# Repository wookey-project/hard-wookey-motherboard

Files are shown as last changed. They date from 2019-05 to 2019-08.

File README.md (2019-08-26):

# WooKey Mainboard PCB

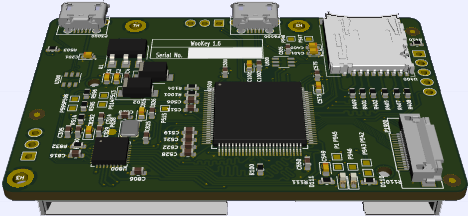
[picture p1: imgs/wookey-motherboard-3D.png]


## Introduction

Wookey | https://wookey-project.github.io/
Copyright 2018 ANSSI

Authors: The Wookey project Team <wookey@ssi.gouv.fr>

The Wookey from [ANSSI](https://www.ssi.gouv.fr) is an open source
hardware design, implementing an Encrypted Flash Drives.

This repository is aimed towards developers.

### Revision information

This directory contains the hardware design for the Wookey board, first public version (Wookey V2).

### PCB editing tools

All PCB files (schematic and PCB layout) have been designed using the KiCad EDA.
This Cross Platform and Open Source Electronics Design Automation Suite can be downloaded
on http://kicad-pcb.org/.

## Production files generation 101

### Configure the project

KiCad binaries location may change regarding your operating system.
This is why you have to set your environment.
This is done by sourcing the `setenv.sh` script. This script exports
all paths that are required in order to automaticaly generate the production files.

Most of the time, the paths proposed in this script are not the one you use in your specific installation.
The `setenv.sh` script support easy variables overloading by including a `setenv.local.sh` script file if this file exists in the same directory.
If you need to overload some of the variables of the `setenv.sh` script, just add them to your own `setenv.local.sh` file.
Here is an example to define KiCad environement path on Apple Mac OS.

```
  $ echo "export PYTHON_BIN_PATH = /Applications/KiCad/kicad.app/Contents/Frameworks/Python.framework/Versions/2.7/bin/python" > setenv.local.sh
  $ source setenv.sh
  Loading local SDK settings...
  =========================================================
  === Kicad environment configuration
  =========================================================
  PYTHON_BIN_PATH   = /Applications/KiCad/kicad.app/Contents/Frameworks/Python.framework/Versions/2.7/bin/python
  PYTHON_PATH     = /Applications/Kicad/kicad.app/Contents/Frameworks/python/site-packages
  BOM_GEN_PATH = /Applications/Kicad/kicad.app/Contents/SharedSupport/plugins/bom2grouped_csv.xsl
  TOOLS_PATH = ../../../tools
  =========================================================
```

The production files can be generated using the following command.

```
$ make
```

This will generate the production files in a new sub directory.
The directory name may differ according the project your are working with.

## PCB Pinout

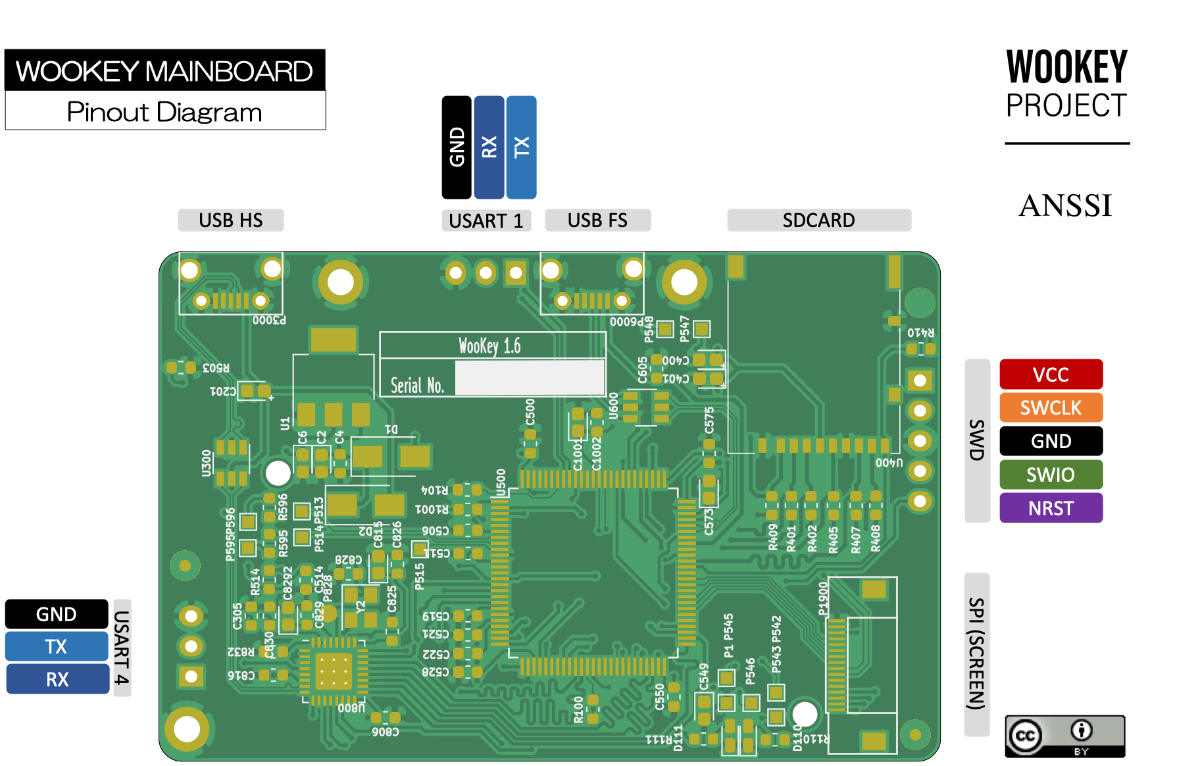
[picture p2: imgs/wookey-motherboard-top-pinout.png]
Pinout


## PCB Layers

### PCB TOP layer

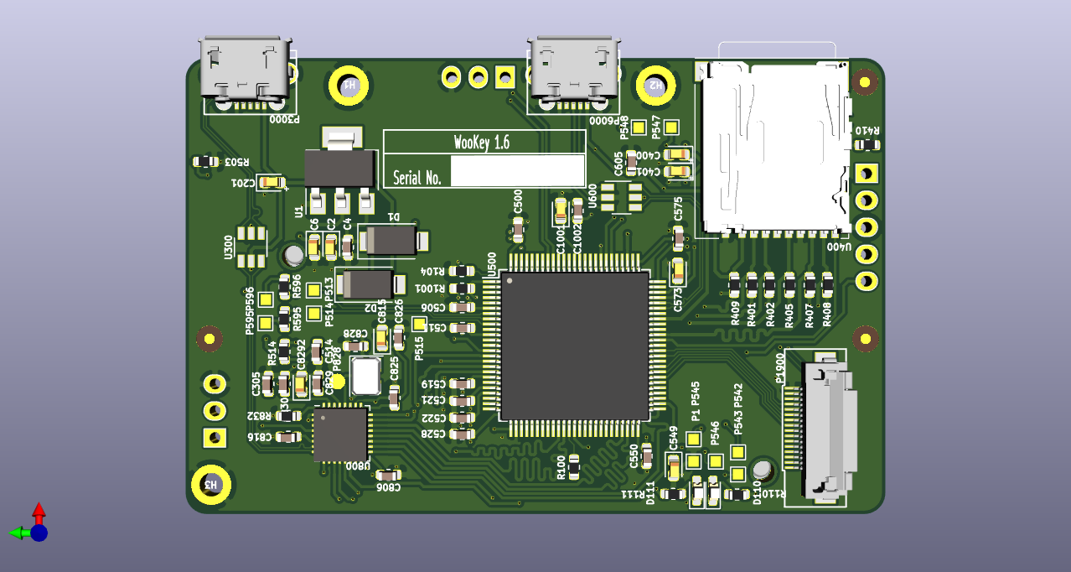
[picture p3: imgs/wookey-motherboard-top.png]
TOP


### PCB BOTTOM layer

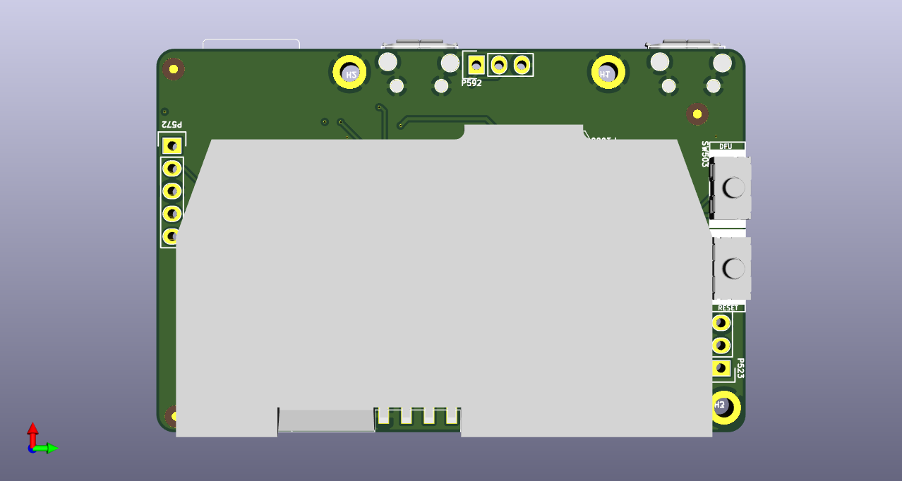
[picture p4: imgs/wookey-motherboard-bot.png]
BOT


### Layers

Order and type of copper layers:
  TOP:  signal, front components
  GND:  ground plane
  PWR:  ground and power plane
  BOT:  signal, back components

### Stackup
4 layers, 1.6mm thickness
Outer layers 1 oz base copper foil
Inner layers 0.5 oz base copper foil

Electroless Nickel Immersion Gold (ENIG) surface finish

solder resist   0.0254mm
copper          0.0356mm    L1 (TOP)
FR408 prepreg   0.1702mm
copper          0.0178mm    L2 (GND)
FR408           1.1938mm
copper          0.0178mm    L3 (PWR)
FR408 prepreg   0.1702mm
copper          0.0356mm    L4 (BOT)
solder resist   0.0254mm

The substrate for both the core and prepreg is FR408,
with a dielectric constant of 3.66 at 1GHz.
The prepreg is comprised of 2 layers of Isola 2113.

## Regulatory compliance & handling

The Wookey board is intended for use as a development platform for hardware
or software. The board is an open system design, which does not include a
shielded enclosure. This may cause interference to other electrical or
electronic devices in close proximity. In a domestic environment, this product
may cause radio interference in which case the user may be required to take
adequate measures. In addition, this board should not be used near any medical
equipment or RF devices.

The board is sensitive to ESD. Hold the board only by its edges. After removing
the board from its box, place it on a grounded, static-free surface.

The board can become hot, like any fan-less design, during continuous high CPU
loads, mind its temperature while handling it.

## License

Wookey | https://wookey-project.github.io/

Copyright 2019 ANSSI

Authors: The Wookey project Team <wookey@ssi.gouv.fr>

This is an open hardware design licensed under the terms of the CERN Open
Hardware Licence (OHL) v1.2.

You may redistribute and modify this documentation under the terms of the CERN
OHL v.1.2 (http://ohwr.org/cernohl). This documentation is distributed WITHOUT
ANY EXPRESS OR IMPLIED WARRANTY, INCLUDING OF MERCHANTABILITY, SATISFACTORY
QUALITY AND FITNESS FOR A PARTICULAR PURPOSE. Please see the CERN OHL v.1.2 for
applicable conditions.

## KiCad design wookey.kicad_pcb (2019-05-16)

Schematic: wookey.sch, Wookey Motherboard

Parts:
FID1, FID2, FID3: FIDUCIAL; Fiducial_1mm_Dia_2.54mm_Outer_CopperTop
FID4, FID5, FID6: FIDUCIAL; Fiducial_1mm_Dia_2.54mm_Outer_CopperBottom
H1: H1; MountingHole_2.2mm_M2_ISO14580_Pad
H2: H2; MountingHole_2.2mm_M2_ISO14580_Pad
H3: H3; MountingHole_2.2mm_M2_ISO14580_Pad

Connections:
GND: H1.1, H2.1, H3.1; also elsewhere on the board

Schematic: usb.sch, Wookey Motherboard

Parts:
C201, C815, C8292: 4.7uF; CP_EIA-1608-08_AVX-J; MFG Part Num TLCJ475M010XTA
C305, C605, C806, C816, C825, C826, C829, C830: 100nF; C_0603_1608Metric; MFG Part Num 0603YC104JAT2A
C828: 0.01uF; C_0603_1608Metric; MFG Part Num C0603C103K2RACTU
P828: XI; Measurement_Point_Round-SMD-Pad_Small
P3000, P6000: USB_FS_OTG; USB_Micro-B-MOLEX_105017-0001; MFG Part Num 105017-0001
R832: 12K [1%]; R_0603_1608Metric; MFG Part Num MCT06030C1202FP500
U300, U600: USBLC6-2; TSOT-23-6; MFG Part Num USBLC6-2SC6
U800: USB3300; QFN-32-1EP_5x5mm_P0.5mm_EP3.1x3.1mm_ThermalVias; MFG Part Num USB3300-EZK
Y2: ASEMB-24.000MHZ-LY-T; Oscillator_SMD_Abracon_ASE-4Pin_3.2x2.5mm; MFG Part Num ASEMB-24.000MHZ-LY-T

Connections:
+3V3: C806.1, C816.1, C825.1, C828.1, C830.1, U800.6 (VDD3.3), U800.16 (VDD3.3), U800.25 (VDD3.3), U800.30 (VDD3.3), U800.31 (REG_EN), Y2.1 (STBY), Y2.4 (Vdd); also elsewhere on the board
/cpu/USB_FS_D+: U600.4 (Out2); also elsewhere on the board
/cpu/USB_FS_D-: U600.6 (Out1); also elsewhere on the board
/cpu/USB_FS_VBUS: C605.1, P6000.1 (VCC), U600.5 (VBUS); also elsewhere on the board
/cpu/USB_HS_HARD_RESET: U800.9 (RESET); also elsewhere on the board
/cpu/USB_HS_ULPI_CLK: U800.14 (CLKOUT); also elsewhere on the board
/cpu/USB_HS_ULPI_D0: U800.24 (DATA0); also elsewhere on the board
/cpu/USB_HS_ULPI_D1: U800.23 (DATA1); also elsewhere on the board
/cpu/USB_HS_ULPI_D2: U800.22 (DATA2); also elsewhere on the board
/cpu/USB_HS_ULPI_D3: U800.21 (DATA3); also elsewhere on the board
/cpu/USB_HS_ULPI_D4: U800.20 (DATA4); also elsewhere on the board
/cpu/USB_HS_ULPI_D5: U800.19 (DATA5); also elsewhere on the board
/cpu/USB_HS_ULPI_D6: U800.18 (DATA6); also elsewhere on the board
/cpu/USB_HS_ULPI_D7: U800.17 (DATA7); also elsewhere on the board
/cpu/USB_HS_ULPI_DIR: U800.12 (DIR); also elsewhere on the board
/cpu/USB_HS_ULPI_NXT: U800.11 (NXT); also elsewhere on the board
/cpu/USB_HS_ULPI_STP: U800.13 (STP); also elsewhere on the board
/cpu/USB_HS_VBUS: C201.2, C305.1, P3000.1 (VCC), U300.5 (VBUS), U800.4 (VBUS); also elsewhere on the board
/usb/USB_FS_CON_D+: P6000.3 (D+), U600.3 (In2)
/usb/USB_FS_CON_D-: P6000.2 (D-), U600.1 (In1)
/usb/USB_HS_CON_D+: P3000.3 (D+), U300.1 (In1)
/usb/USB_HS_CON_D-: P3000.2 (D-), U300.3 (In2)
/usb/USB_HS_D+: U300.6 (Out1), U800.7 (D+)
/usb/USB_HS_D-: U300.4 (Out2), U800.8 (D-)
GND: C201.1, C305.2, C605.2, C806.2, C815.2, C816.2, C825.2, C826.2, C828.2, C829.2, C830.2, C8292.2, P3000.5 (GND), P3000.6 (shield), P6000.5 (GND), P6000.6 (shield), R832.2, U300.2 (GND), U600.2 (GND), U800.1 (GND), U800.2 (GND), U800.33 (GND), Y2.2 (GND); also elsewhere on the board
unnamed: C815.1, C826.1, U800.15 (VDD1.8), U800.26 (VDD1.8)
unnamed: C829.1, C8292.1, U800.29 (VDDA1.8)
unnamed: P828.1, U800.28 (XI), Y2.3 (OUT)
unnamed: R832.1, U800.32 (RBIAS)

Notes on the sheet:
USB HIGH SPEED
USB FULLSPEED
Optional active high transceiver reset. This is the same as a write to the ULPI Reset, address 04h, bit 5. This does not reset the ULPI register set. This pin includes an integrated pull-down resistor to ground. If not used, this pin can be floated or connected to ground (recommended).
see qtzcry-app-notes.pdf (in datasheets)

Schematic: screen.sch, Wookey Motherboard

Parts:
BOM-ONLY1: FFC Jumper Cable; 0.5mm; 50mm; MFG Part Num 687716050002
BOM-ONLY2: FFC Jumper Cable; 0.5mm; 100mm; MFG Part Num 687716100002
BOM-ONLY3: FFC Jumper Cable; 0.5mm; 152mm; MFG Part Num 98266-0172
P1900: CONN_FPC16; FPC16_MOLEX_52892_1633; MFG Part Num 52892-1633

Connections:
+3V3: P1900.1; also elsewhere on the board
/cpu/SCREEN_~D~C: P1900.12; also elsewhere on the board
/cpu/SPI_MISO: P1900.3; also elsewhere on the board
/cpu/SPI_MOSI: P1900.2; also elsewhere on the board
/cpu/SPI_SCK: P1900.4; also elsewhere on the board
/cpu/TOUCH_BUSY: P1900.10; also elsewhere on the board
/cpu/TOUCH_IRQ: P1900.11; also elsewhere on the board
/cpu/~SPI_FLASH_CS: P1900.7; also elsewhere on the board
/cpu/~SPI_FONT_CS: P1900.8; also elsewhere on the board
/cpu/~SPI_SCREEN_CS: P1900.14; also elsewhere on the board
/cpu/~SPI_TOUCH_CS: P1900.9; also elsewhere on the board
/screen/SCREEN_RESET: P1900.13; also elsewhere on the board
GND: P1900.16; also elsewhere on the board

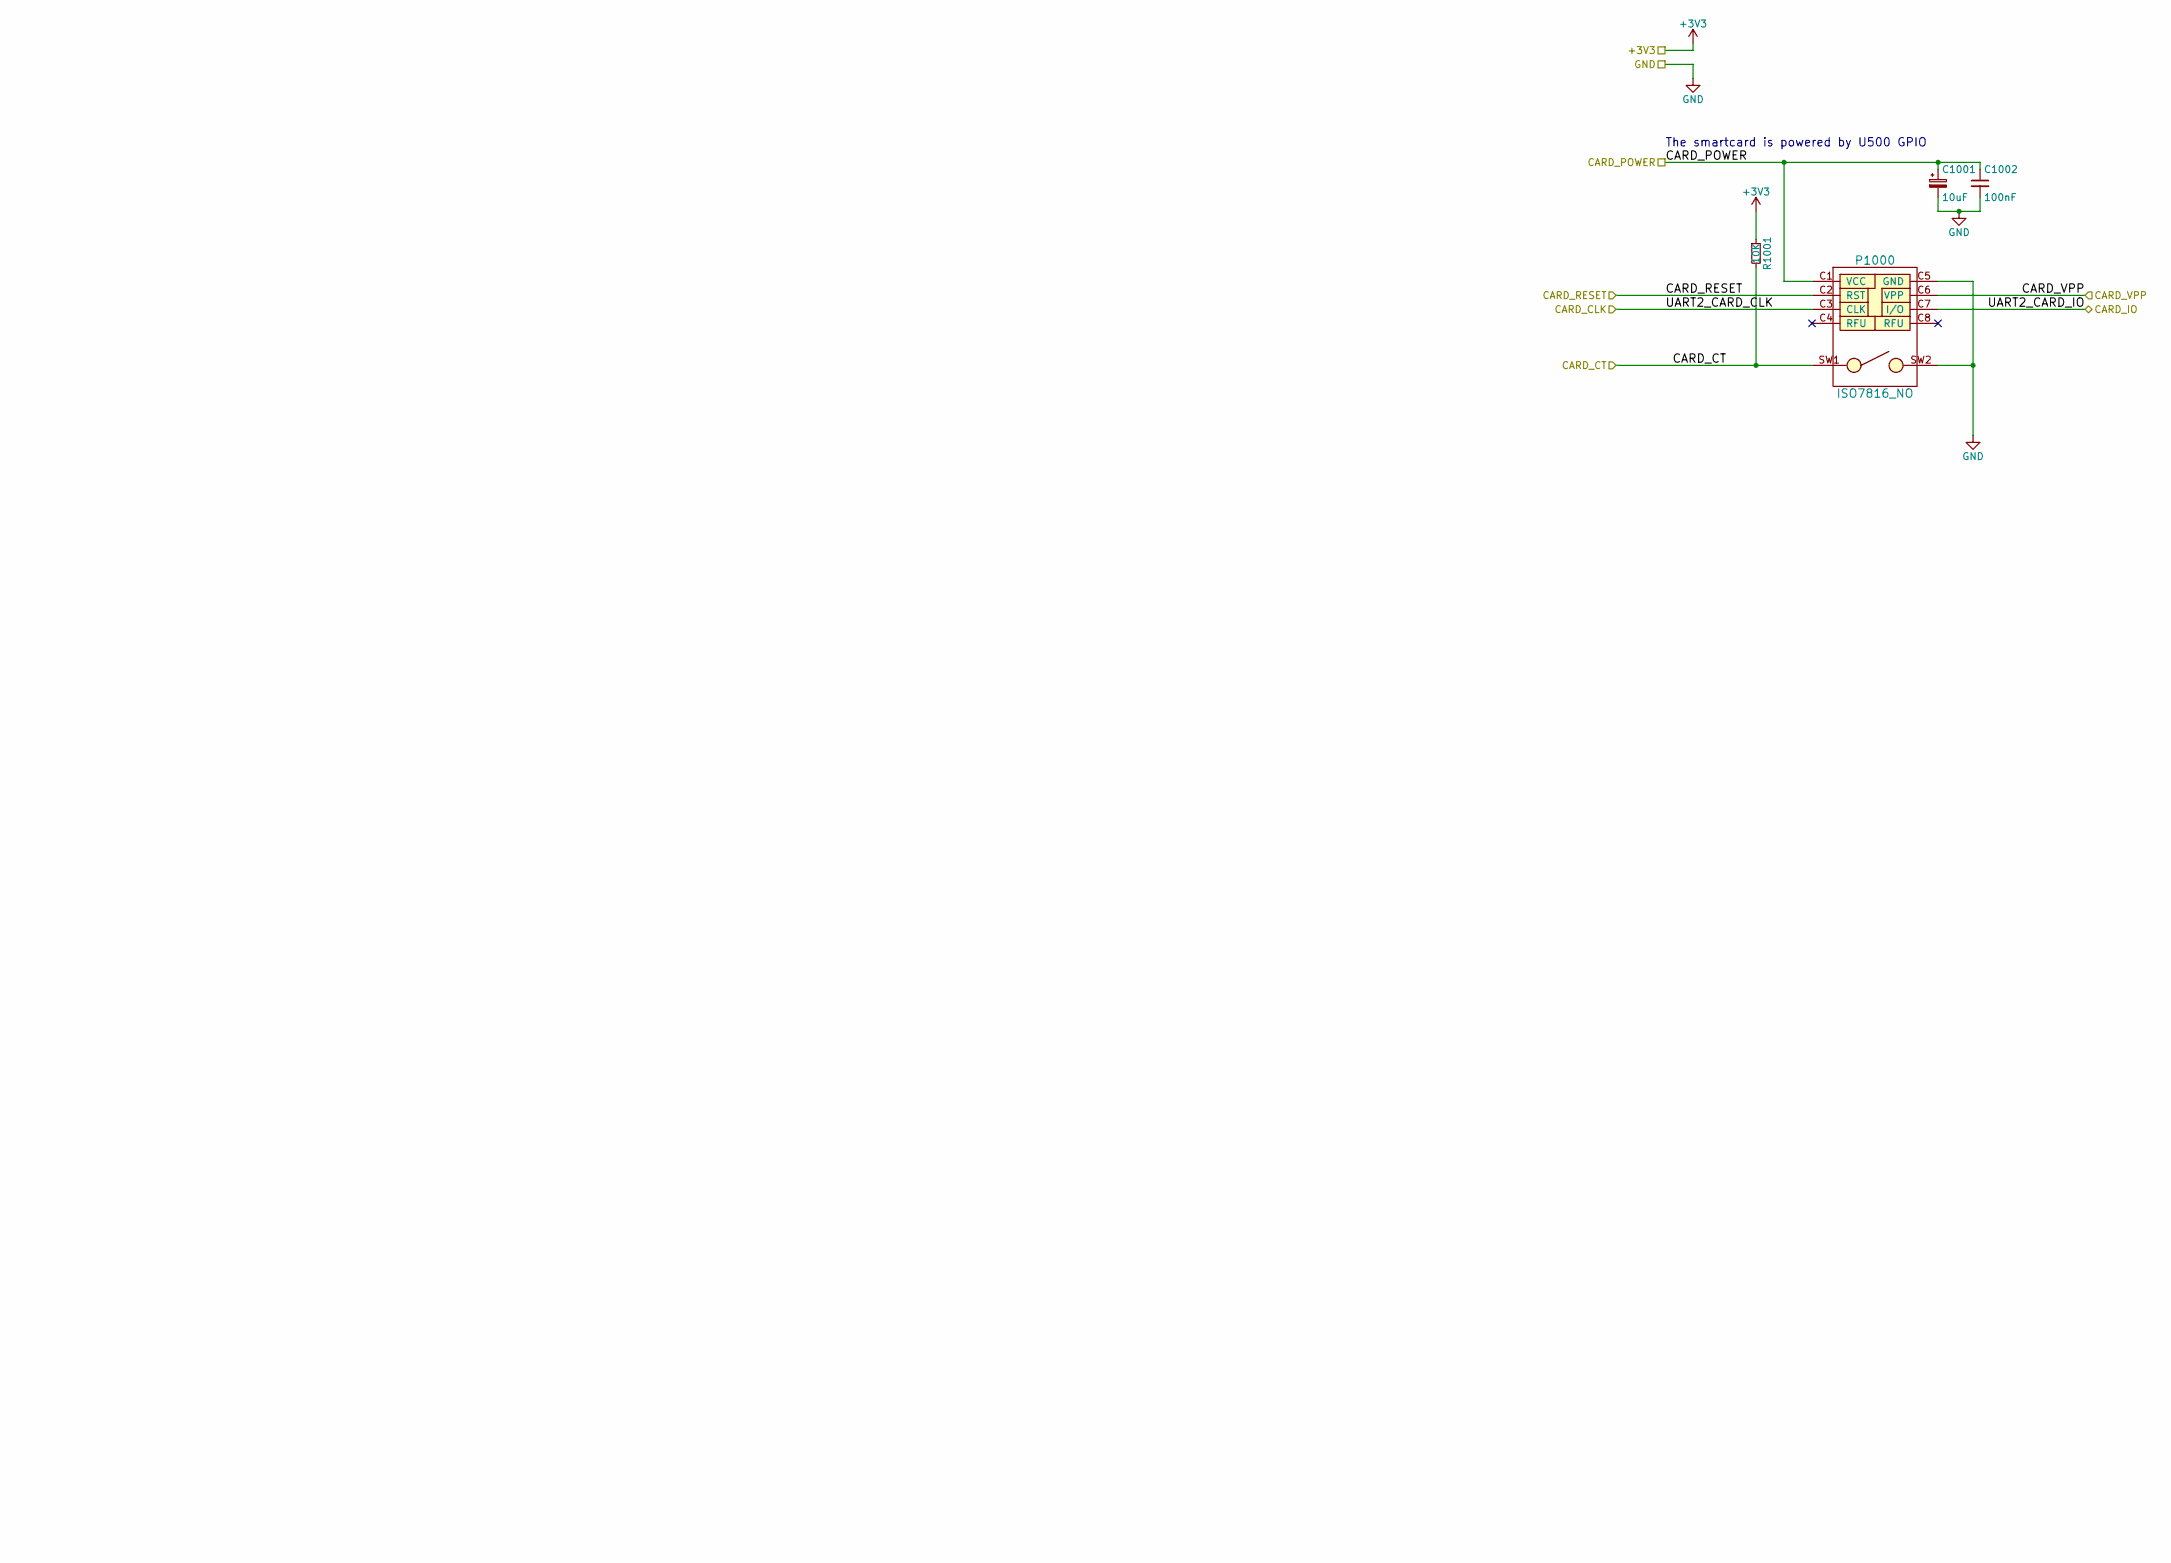
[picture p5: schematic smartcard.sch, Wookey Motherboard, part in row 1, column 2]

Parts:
C1001: 10uF; CP_EIA-1608-08_AVX-J; MFG Part Num F981A106MMA
C1002: 100nF; C_0603_1608Metric; MFG Part Num 0603YC104JAT2A
P1000: ISO7816_NO; VJW53666; MFG Part Num 7312P0225A13LF
R1001: 10K; R_0603_1608Metric; MFG Part Num CRCW060310K0FKEAHP

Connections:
+3V3: R1001.1; also elsewhere on the board
/cpu/CARD_CLK: P1000.C3 (CLK); also elsewhere on the board
/cpu/CARD_CT: P1000.SW1, R1001.2; also elsewhere on the board
/cpu/CARD_IO: P1000.C7 (I/O); also elsewhere on the board
/cpu/CARD_POWER: C1001.1, C1002.1, P1000.C1 (VCC); also elsewhere on the board
/cpu/CARD_RESET: P1000.C2 (RST); also elsewhere on the board
/cpu/CARD_VPP: P1000.C6 (VPP); also elsewhere on the board
GND: C1001.2, C1002.2, P1000.C5 (GND), P1000.SW2; also elsewhere on the board

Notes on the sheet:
The smartcard is powered by U500 GPIO

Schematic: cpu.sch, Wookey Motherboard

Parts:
C2, C6: 10uF; CP_EIA-1608-08_AVX-J; MFG Part Num F981A106MMA
C4, C500, C506, C511, C514, C519, C521, C522, C528, C550, C575: 100nF; C_0603_1608Metric; MFG Part Num 0603YC104JAT2A
C549, C573: 2.2uF; CP_EIA-1608-08_AVX-J; MFG Part Num TACL225M016XTA
D1, D2: STPS1L30A; D_SMA; MFG Part Num STPS1L30A
D110: LED BLUE; LED_0603_1608Metric_Castellated; MFG Part Num VLMB1300-GS08
D111: LED GREEN; LED_0603_1608Metric_Castellated; MFG Part Num VLMTG1300-GS08
P1: GND; TestPoint_Pad_1.0x1.0mm
P513: TP1; TestPoint_Pad_1.0x1.0mm
P514: TP2; TestPoint_Pad_1.0x1.0mm
P515: TP3; TestPoint_Pad_1.0x1.0mm
P523: UART4; Pin_Header_Straight_1x03; MFG Part Num 90121-0763
P542: TP4; TestPoint_Pad_1.0x1.0mm
P543: TP5; TestPoint_Pad_1.0x1.0mm
P545: TP7; TestPoint_Pad_1.0x1.0mm
P546: TP8; TestPoint_Pad_1.0x1.0mm
P547: TP9; TestPoint_Pad_1.0x1.0mm
P548: TP10; TestPoint_Pad_1.0x1.0mm
P572: DEBUG/PROG; Pin_Header_Straight_1x05; MFG Part Num TSW-105-07-L-S
P592: UART1; Pin_Header_Straight_1x03; MFG Part Num 90121-0763
P595: I2C1_SCL; TestPoint_Pad_1.0x1.0mm
P596: I2C1_SDA; TestPoint_Pad_1.0x1.0mm
R100, R503, R514: 10K; R_0603_1608Metric; MFG Part Num CRCW060310K0FKEAHP
R104, R110, R111: 470; R_0603_1608Metric; MFG Part Num CRCW0603470RFKEA
R595, R596: 47K; R_0603_1608Metric; MFG Part Num CRCW060347K0FKEA
SW503: DFU; KSR_TACTILE_SWITCH; MFG Part Num KSR231G LFS
SW514: RESET; KSR_TACTILE_SWITCH; MFG Part Num KSR231G LFS
U1: LD1117S33TR; SOT-223; MFG Part Num LD1117S33TR
U500: STM32F439VIT6; LQFP-100_14x14mm_Pitch0.5mm; MFG Part Num STM32F439VIT6

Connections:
+3V3: C6.1, C500.1, C506.1, C511.1, C519.1, C521.1, C522.1, C528.1, C550.1, C575.1, P572.1, R100.1, R514.1, R595.1, R596.1, SW503.1, U1.2 (VO), U500.6 (VBAT), U500.11 (VDD), U500.19 (VDD), U500.21 (VREF+), U500.22 (VDDA), U500.28 (VDD), U500.50 (VDD), U500.75 (VDD), U500.100 (VDD); also elsewhere on the board
+5V: C2.1, C4.1, D1.1 (K), D2.1 (K), U1.3 (VI)
/cpu/BOOT0: R104.1, U500.94 (BOOT0)
/cpu/BOOT1: R100.2, U500.37 (PB2)
/cpu/CARD_CLK: U500.29 (PA4); also elsewhere on the board
/cpu/CARD_CT: U500.1 (PE2); also elsewhere on the board
/cpu/CARD_IO: U500.25 (PA2); also elsewhere on the board
/cpu/CARD_POWER: U500.88 (PD7); also elsewhere on the board
/cpu/CARD_RESET: U500.2 (PE3); also elsewhere on the board
/cpu/CARD_VPP: U500.38 (PE7); also elsewhere on the board
/cpu/DFU: R503.1, SW503.2, U500.3 (PE4)
/cpu/I2C1_SCL_PB8: P595.1, R595.2
/cpu/I2C1_SDA_PB9: P596.1, R596.2
/cpu/NRST: C514.1, P572.5, R514.2, SW514.1, U500.14 (NRST)
/cpu/SCREEN_~D~C: U500.61 (PD14); also elsewhere on the board
/cpu/SD_CLK: U500.80 (PC12); also elsewhere on the board
/cpu/SD_CMD: U500.83 (PD2); also elsewhere on the board
/cpu/SD_D0: U500.65 (PC8); also elsewhere on the board
/cpu/SD_D1: U500.66 (PC9); also elsewhere on the board
/cpu/SD_D2: U500.78 (PC10); also elsewhere on the board
/cpu/SD_D3: U500.79 (PC11); also elsewhere on the board
/cpu/SD_D7: U500.64 (PC7); also elsewhere on the board
/cpu/SPI_MISO: U500.53 (PB14); also elsewhere on the board
/cpu/SPI_MOSI: U500.54 (PB15); also elsewhere on the board
/cpu/SPI_SCK: U500.84 (PD3); also elsewhere on the board
/cpu/TCK/SWCLK: P572.2, U500.76 (PA14)
/cpu/TMS/SWIO: P572.4, U500.72 (PA13)
/cpu/TOUCH_BUSY: U500.58 (PD11); also elsewhere on the board
/cpu/TOUCH_IRQ: U500.59 (PD12); also elsewhere on the board
/cpu/TP1: P513.1, U500.7 (PC13)
/cpu/TP2: P514.1, U500.8 (PC14)
/cpu/TP3: P515.1, U500.9 (PC15)
/cpu/UART1_RX_PB7: P592.2, U500.93 (PB7)
/cpu/UART1_TX_PB6: P592.1, U500.92 (PB6)
/cpu/UART4_RX_PA1: P523.1, U500.24 (PA1)
/cpu/UART4_TX_PA0: P523.2, U500.23 (PA0)
/cpu/USB_FS_D+: U500.71 (PA12); also elsewhere on the board
/cpu/USB_FS_D-: U500.70 (PA11); also elsewhere on the board
/cpu/USB_FS_VBUS: D1.2 (A), U500.68 (PA9); also elsewhere on the board
/cpu/USB_HS_HARD_RESET: U500.16 (PC1); also elsewhere on the board
/cpu/USB_HS_ULPI_CLK: U500.30 (PA5); also elsewhere on the board
/cpu/USB_HS_ULPI_D0: U500.26 (PA3); also elsewhere on the board
/cpu/USB_HS_ULPI_D1: U500.35 (PB0); also elsewhere on the board
/cpu/USB_HS_ULPI_D2: U500.36 (PB1); also elsewhere on the board
/cpu/USB_HS_ULPI_D3: U500.47 (PB10); also elsewhere on the board
/cpu/USB_HS_ULPI_D4: U500.48 (PB11); also elsewhere on the board
/cpu/USB_HS_ULPI_D5: U500.51 (PB12); also elsewhere on the board
/cpu/USB_HS_ULPI_D6: U500.52 (PB13); also elsewhere on the board
/cpu/USB_HS_ULPI_D7: U500.91 (PB5); also elsewhere on the board
/cpu/USB_HS_ULPI_DIR: U500.17 (PC2); also elsewhere on the board
/cpu/USB_HS_ULPI_NXT: U500.18 (PC3); also elsewhere on the board
/cpu/USB_HS_ULPI_STP: U500.15 (PC0); also elsewhere on the board
/cpu/USB_HS_VBUS: D2.2 (A); also elsewhere on the board
/cpu/~SPI_FLASH_CS: U500.86 (PD5); also elsewhere on the board
/cpu/~SPI_FONT_CS: U500.87 (PD6); also elsewhere on the board
/cpu/~SPI_SCREEN_CS: U500.69 (PA10); also elsewhere on the board
/cpu/~SPI_TOUCH_CS: U500.57 (PD10); also elsewhere on the board
/screen/SCREEN_RESET: U500.62 (PD15); also elsewhere on the board
GND: C2.2, C4.2, C6.2, C500.2, C506.2, C511.2, C514.2, C519.2, C521.2, C522.2, C528.2, C549.2, C550.2, C573.2, C575.2, D110.1 (K), D111.1 (K), P1.1, P523.3, P572.3, P592.3, R104.2, R503.2, SW514.2, U1.1 (GND), U500.10 (VSS), U500.20 (VSSA), U500.27 (VSS), U500.74 (VSS), U500.99 (VSS); also elsewhere on the board
LED0: R111.1, U500.33 (PC4)
LED1: R110.1, U500.34 (PC5)
unnamed: C549.1, U500.49 (VCAP_1)
unnamed: C573.1, U500.73 (VCAP_2)
unnamed: D110.2 (A), R110.2
unnamed: D111.2 (A), R111.2
unnamed: P542.1, U500.42 (PE11)
unnamed: P543.1, U500.43 (PE12)
unnamed: P545.1, U500.45 (PE14)
unnamed: P546.1, U500.46 (PE15)
unnamed: P547.1, U500.81 (PD0)
unnamed: P548.1, U500.82 (PD1)

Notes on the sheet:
BOOT MODE
LED
POWER
EXTENSION & DEBUG
Boot0 = 0 => Flash memory aliased at 0x0000000

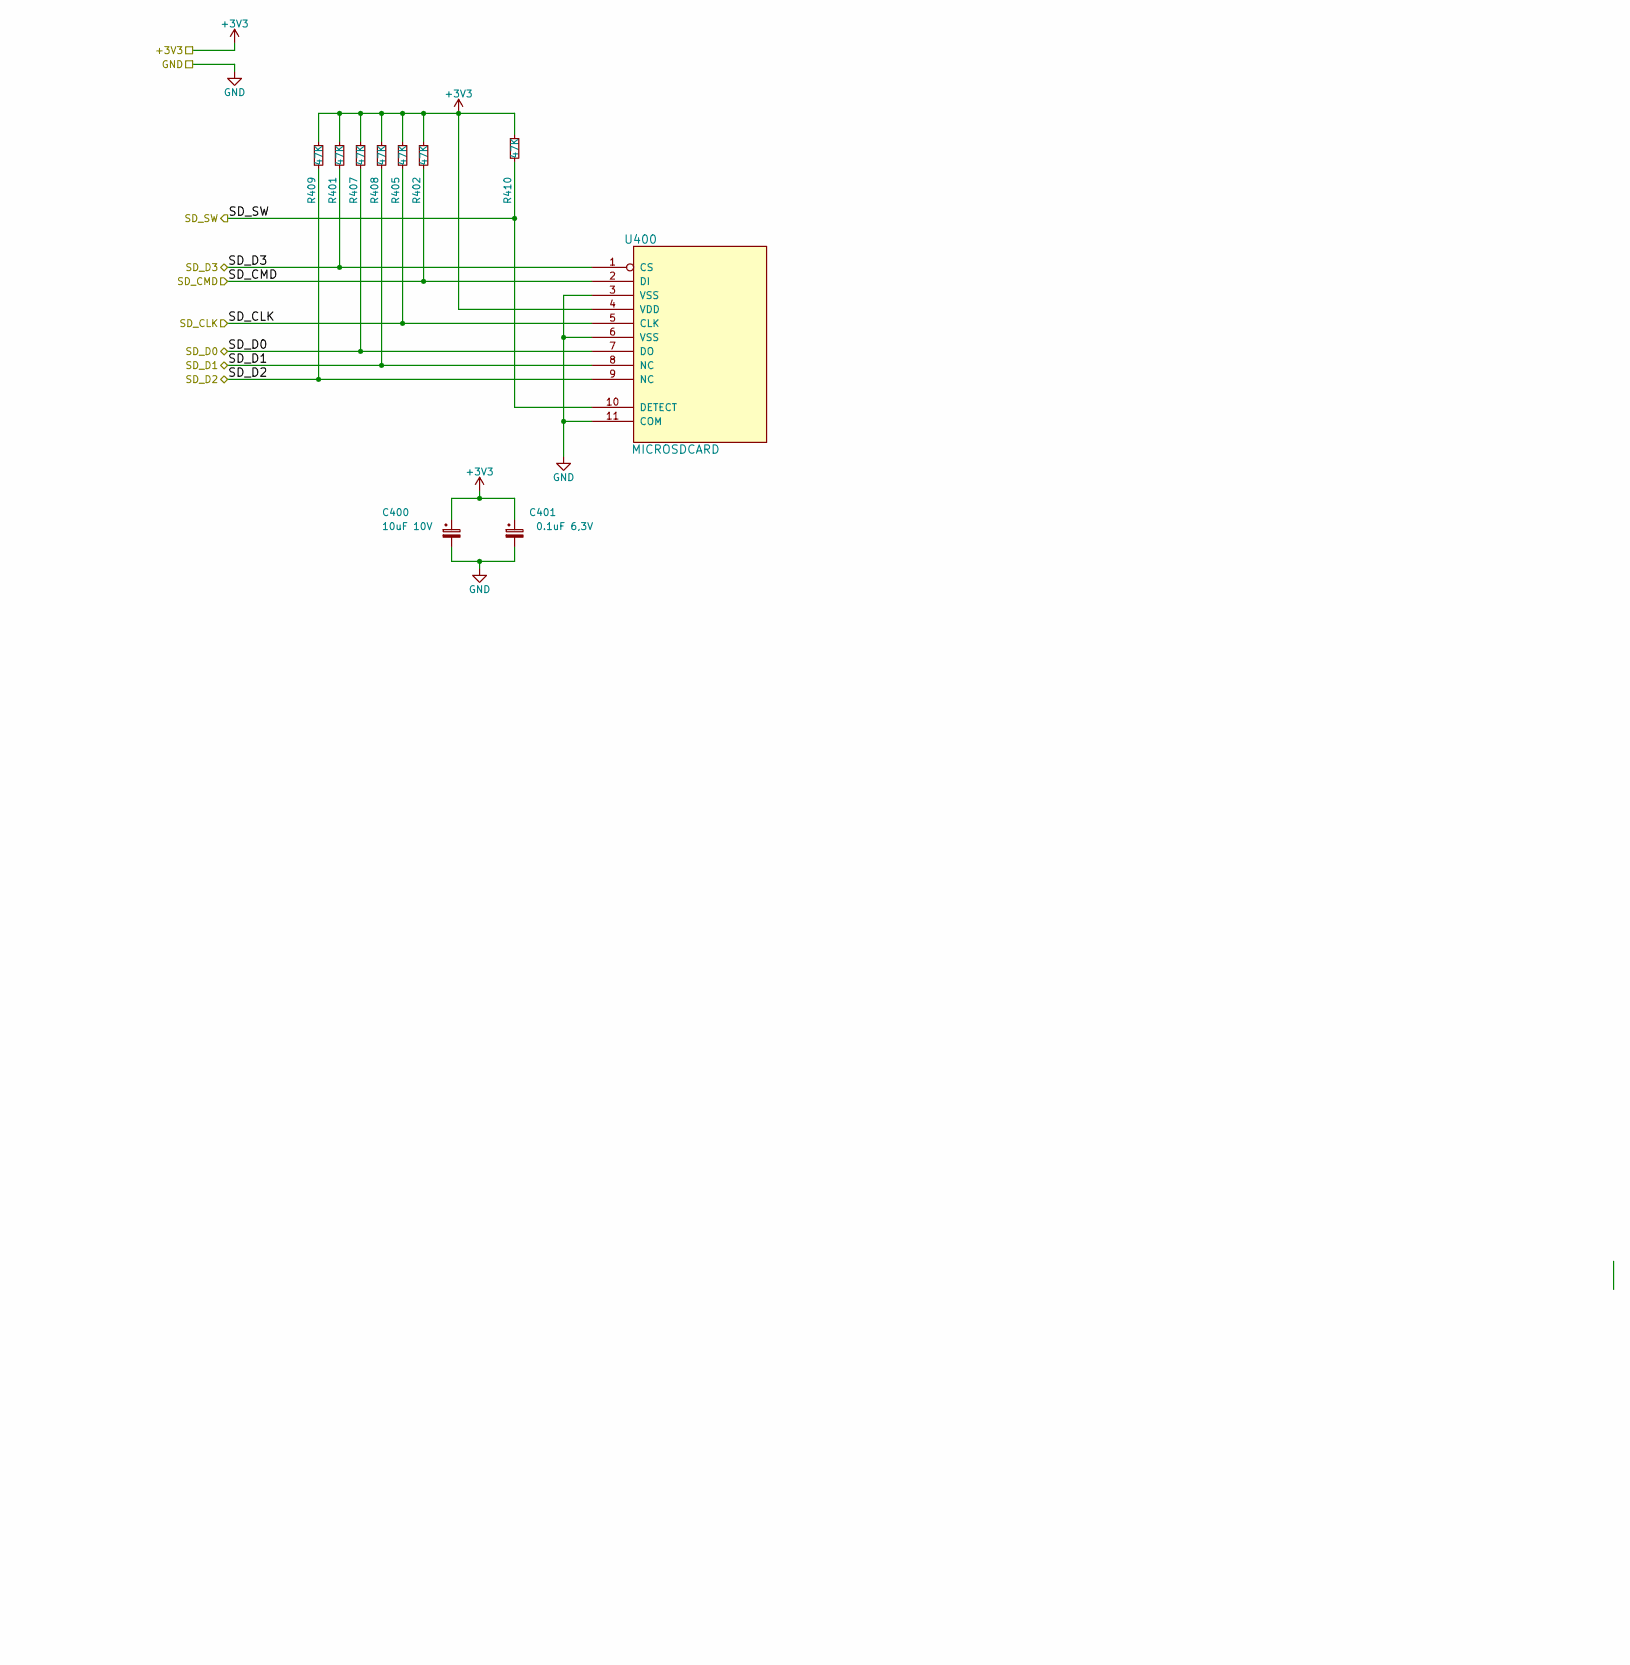
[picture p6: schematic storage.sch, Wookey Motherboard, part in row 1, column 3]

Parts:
C400: 10uF 10V; CP_EIA-1608-08_AVX-J; MFG Part Num TP8M106M6R3C
C401: 0.1uF 6,3V; CP_EIA-1608-08_AVX-J; MFG Part Num 02016D104KAT2A
R401, R402, R405, R407, R408, R409, R410: 47K; R_0603_1608Metric; MFG Part Num CRCW060347K0FKEA
U400: MICROSDCARD; SDCARD_DM3AT; MFG Part Num DM3AT-SF-PEJM5

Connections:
+3V3: C400.1, C401.1, R401.1, R402.1, R405.1, R407.1, R408.1, R409.1, R410.1, U400.4 (VDD); also elsewhere on the board
/cpu/SD_CLK: R405.2, U400.5 (CLK); also elsewhere on the board
/cpu/SD_CMD: R402.2, U400.2 (DI); also elsewhere on the board
/cpu/SD_D0: R407.2, U400.7 (DO); also elsewhere on the board
/cpu/SD_D1: R408.2, U400.8 (NC); also elsewhere on the board
/cpu/SD_D2: R409.2, U400.9 (NC); also elsewhere on the board
/cpu/SD_D3: R401.2, U400.1 (CS); also elsewhere on the board
/cpu/SD_D7: R410.2, U400.10 (DETECT); also elsewhere on the board
GND: C400.2, C401.2, U400.3 (VSS), U400.6 (VSS), U400.11 (COM); also elsewhere on the board

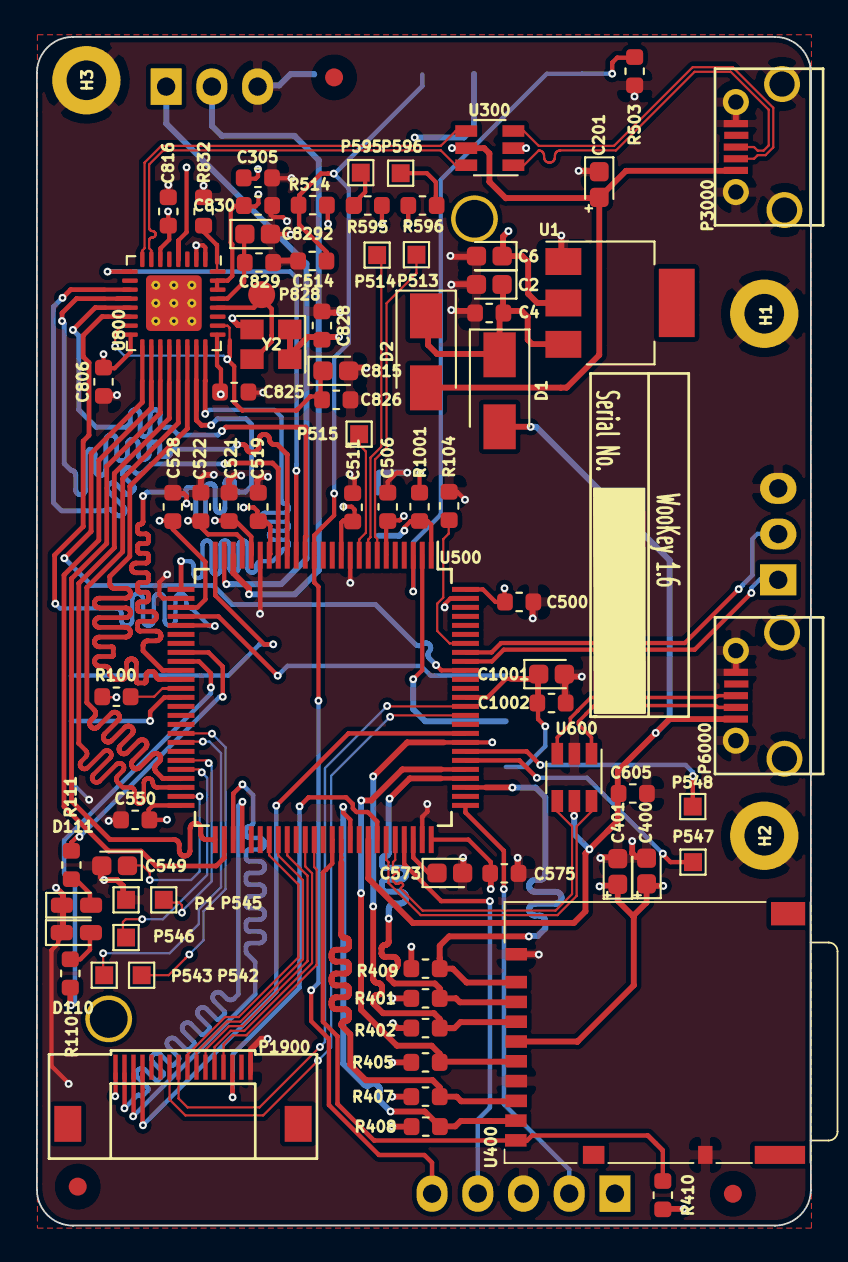
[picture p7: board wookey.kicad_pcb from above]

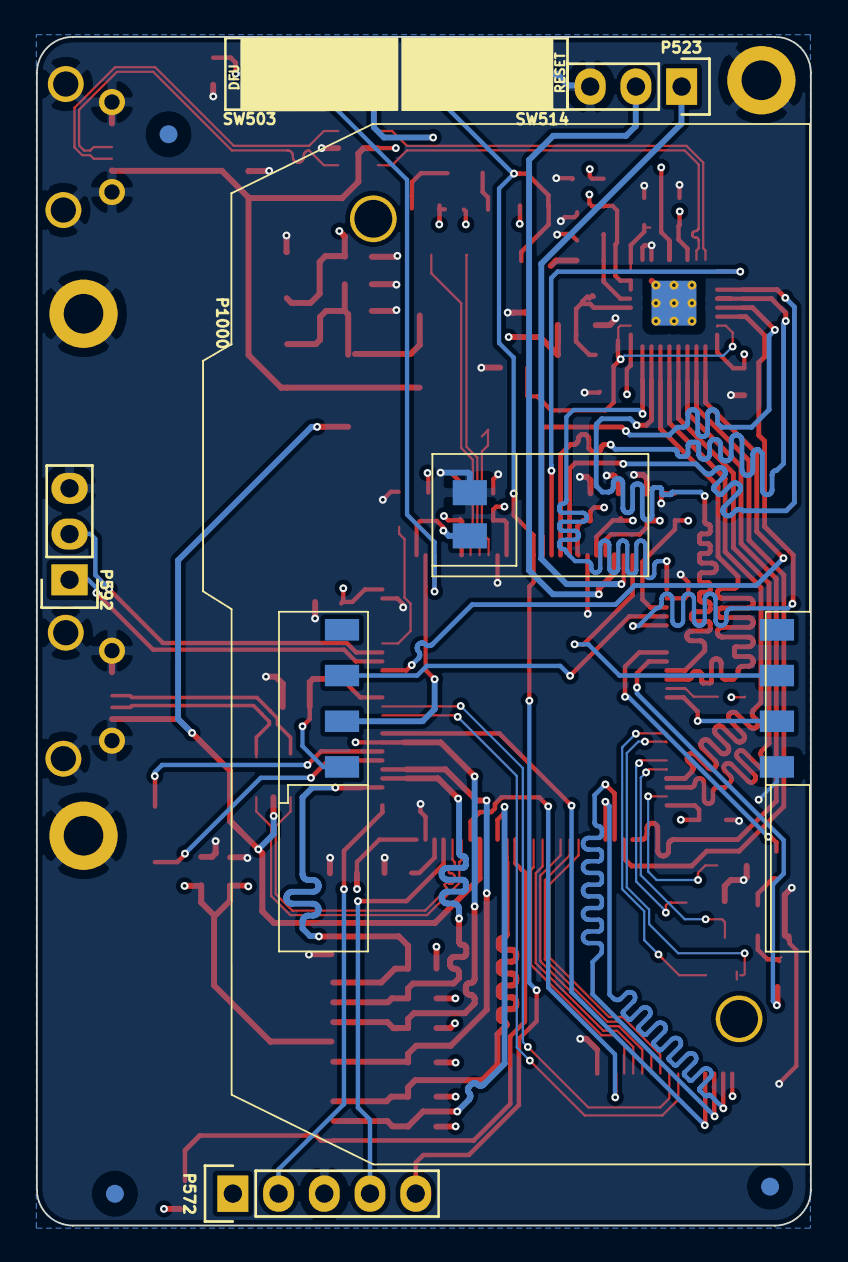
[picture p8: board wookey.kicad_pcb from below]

Board: 4 copper layers, 43.0 x 66.0 mm, 90 parts (6 on the bottom side), 81 nets.

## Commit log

2019-05-15 First import
    [cpu.sch, screen.sch, smartcard.sch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]
2019-05-16 [enhancement] add pcb screenshots
    [wookey.kicad_pcb]
2019-05-16 [enhancement] Reference LICENSE in files
    [cpu.sch, screen.sch, smartcard.sch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]
2019-05-16 [enhancement] General cleanup
    [wookey.kicad_pcb]

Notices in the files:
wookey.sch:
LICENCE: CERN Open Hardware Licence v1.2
